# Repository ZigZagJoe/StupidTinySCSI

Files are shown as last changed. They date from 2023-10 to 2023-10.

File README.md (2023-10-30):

StupidTinySCSI
Derived from ZuliSCSI Pico OSHW.

This should be good but has not been 100% validated.

See below for orginal document.....

ZuluSCSI™ Pico Community Edition - Open Source Hardware
========================

This repository contains the KiCAD 7 schematic and PCB design files for the Pico-based ZuluSCSI™ SCSI to SD storage emulator, which is derived from the ZuluSCSI RP2040 board design. Firmware for ZuluSCSI is available at http://github.com/ZuluSCSI/ZuluSCSI-firmware.

This hardware design is licensed under the terms of the strongly reciprocal CERN OHL-S V2 license, which can be viewed in full at https://ohwr.org/cern_ohl_s_v2.txt and https://ohwr.org/cern_ohl_s_v2.pdf. 

ZuluSCSI™ is a registered trademark of Rabbit Hole Computing, and may not be used commercially without the express written consent of Rabbit Hole Computing. Individuals producing ZuluSCSI boards for personal use are hereby granted permission to use the ZuluSCSI trademark in a noncommercial capacity.

_Any_ use of the ZuluSCSI trademark in a **commercial** context requires prior written consent from Rabbit Hole Computing.

ZuluSCSI Pico OSHW board Render (top)

Firmware for ZuluSCSI is licensed under the GNU GPL Version 3, and can be found at https://github.com/zuluscsi/ZuluSCSI-firmware

Generating fabrication files
----------------------------

The component part numbers are stored in KiCAD schematic.
Manufacturing files, including assembly BOM, can be generated using [KiKit](https://github.com/yaqwsx/KiKit).

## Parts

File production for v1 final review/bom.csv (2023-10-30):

Designator | Footprint | Quantity | Value | LCSC Part #
C101, C103, C104, C105, C106, C107, C312 | 0603 | 7 | 100nF | C14663
C111, C209, C211, C215 | 0603 | 4 | 12pF | C38523
C114, C201, C207, C210, C303, C322 | 0805 | 6 | 10uF | C15850
C203, C301, C302 | CP_EIA-6032-15_Kemet-U_Pad2.25x2.35mm_HandSolder | 3 | 220uF
D201, D203, D204 | D_SOD-123 | 3 | D_Schottky | C8598
D302 | 0805 | 1 | LED | C434435
F202 | 1206 | 1 | 500mA Hold | C369160
J101 | DSUB-25_Female_Horizontal_P2.77x2.84mm_EdgePinOffset9.90mm_Housed_MountingHolesOffset11.32mm | 1 | DB25_Female_MountingHoles | N/A
J301 | microSD_HC_Hirose_DM3AT-SF-PEJM5 | 1 | Micro_SD_Card_Det_Hirose_DM3AT
JP301 | SolderJumper-2_P1.3mm_Bridged_RoundedPad1.0x1.5mm | 1 | SCSI_TERM
L201 | Inductor_1008 | 1 | 2.2uH | C86092
L202, L301 | 0603 | 2 | Ferrite_Bead_Small | C1002
R109, R110, R119 | 0603 | 3 | 110 | C22781
R122, R123, R124, R125, R301, R317 | 0603 | 6 | 1k | C21190
R126, R127, R128, R129, R205, R307, R308, R311, R312, R313, R314, R315, R318 | 0603 | 13 | 4k7 | C23162
R201 | 0603 | 1 | 510k | C23192
R202 | 0603 | 1 | 100k | C25803
R304 | 0603 | 1 | 62 | C25252
RN301, RN302 | R_Array_Convex_8x0602 | 2 | 110
U1 | RPi_Pico_WH_headers | 1 | Pico W | N/A
U101, U102, U103 | SSOP_TSSOP-14_4.4x5mm_Pitch0.65mm_PCBWay-MaskClearance0.22mm | 3 | 74LVT125 | C7042
U105, U106 | SSOP_TSSOP-20_5.3x7.2mm_P0.65mm | 2 | 74LVT245 | C7057
U201 | TSOT-23-5 | 1 | LM3674-ADJ | C52027

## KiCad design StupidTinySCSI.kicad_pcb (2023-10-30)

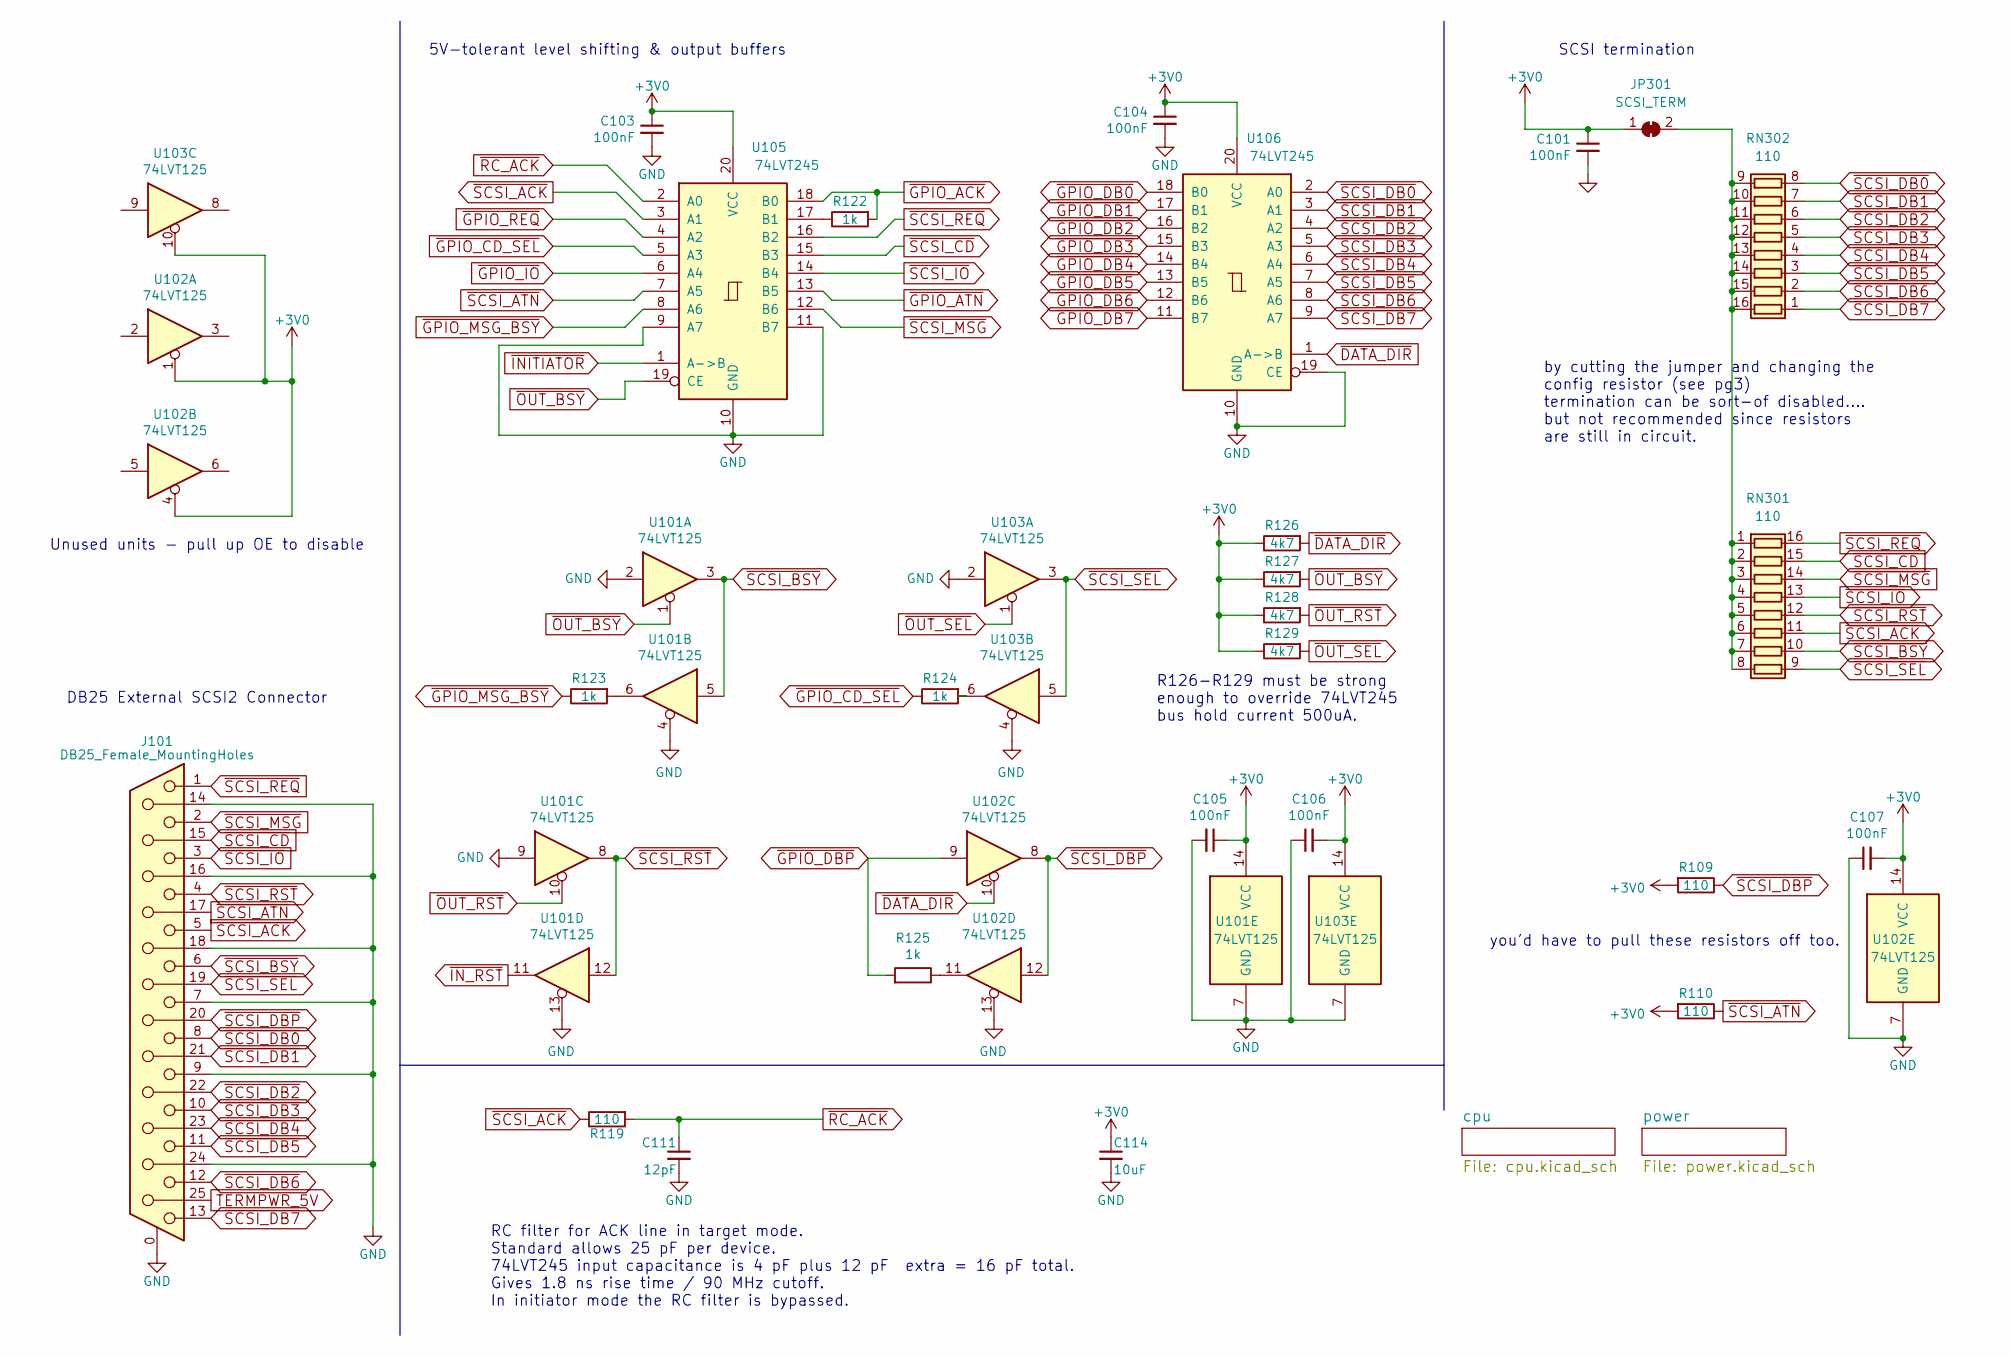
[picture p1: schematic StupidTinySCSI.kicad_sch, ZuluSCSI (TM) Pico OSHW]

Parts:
C101, C103, C104, C105, C106, C107: 100nF; C_0603_1608Metric; PartNumber CL10B104KB8NNWC; LCSC C14663
C111: 12pF; C_0603_1608Metric; PartNumber C0603C120J5GAC7867; LCSC C38523
C114: 10uF; C_0805_2012Metric; PartNumber CL21A106KPFNNNG; LCSC C15850
J101: DB25_Female_MountingHoles; DSUB-25_Female_Horizontal_P2.77x2.84mm_EdgePinOffset9.90mm_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; LCSC N/A
JP301: SCSI_TERM; SolderJumper-2_P1.3mm_Bridged_RoundedPad1.0x1.5mm
R109, R110, R119: 110; R_0603_1608Metric; PartNumber RC0603FR-07110RL; LCSC C22781
R122, R123, R124, R125: 1k; R_0603_1608Metric; PartNumber RC0603JR-071KL; LCSC C21190
R126, R127, R128, R129: 4k7; R_0603_1608Metric; PartNumber RC0603JR-074K7L; LCSC C23162
RN301, RN302: 110; R_Array_Convex_8x0602
U101, U102, U103: 74LVT125; SSOP_TSSOP-14_4.4x5mm_Pitch0.65mm_PCBWay-MaskClearance0.22mm; PartNumber 74LVTH125MTC; LCSC C7042
U105, U106: 74LVT245; SSOP_TSSOP-20_5.3x7.2mm_P0.65mm; PartNumber 74LVT245BBT20-13; LCSC C7057

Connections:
+3V0: C101.1, C103.1, C104.1, C105.1, C106.2, C107.2, C114.1, JP301.1 (A), R109.2, R110.2, R126.1, R127.1, R128.1, R129.1, U101.14 (VCC), U102.1, U102.4, U102.14 (VCC), U103.10, U103.14 (VCC), U105.20 (VCC), U106.20 (VCC); also elsewhere on the board
GND: C101.2, C103.2, C104.2, C105.2, C106.1, C107.1, C111.2, C114.2, J101.0 (PAD), J101.7, J101.9, J101.14, J101.16, J101.18, J101.24, U101.2, U101.4, U101.7 (GND), U101.9, U101.13, U102.7 (GND), U102.13, U103.2, U103.4, U103.7 (GND), U105.9 (A7), U105.10 (GND), U105.11 (B7), U106.10 (GND), U106.19 (CE); also elsewhere on the board
unnamed: JP301.2 (B), RN301.1 (R1.1), RN301.2 (R2.1), RN301.3 (R3.1), RN301.4 (R4.1), RN301.5 (R5.1), RN301.6 (R6.1), RN301.7 (R7.1), RN301.8 (R8.1), RN302.9 (R8.2), RN302.10 (R7.2), RN302.11 (R6.2), RN302.12 (R5.2), RN302.13 (R4.2), RN302.14 (R3.2), RN302.15 (R2.2), RN302.16 (R1.2)
unnamed: R123.2, U101.6
unnamed: R124.2, U103.6
unnamed: R125.1, U102.11
unnamed: R122.1, U105.17 (B1)
TERMPWR_5V: J101.25; also elsewhere on the board
~DATA_DIR: R126.2, U102.10, U106.1 (A->B); also elsewhere on the board
~DBGLOG: U105.4 (A2); also elsewhere on the board
~GPIO_ACK: R122.2, U105.18 (B0); also elsewhere on the board
~GPIO_ATN: U105.1 (A->B), U105.13 (B5); also elsewhere on the board
~GPIO_CD_SEL: R124.1, U105.5 (A3); also elsewhere on the board
~GPIO_DB0: U106.18 (B0); also elsewhere on the board
~GPIO_DB1: U106.17 (B1); also elsewhere on the board
~GPIO_DB2: U106.16 (B2); also elsewhere on the board
~GPIO_DB3: U106.15 (B3); also elsewhere on the board
~GPIO_DB4: U106.14 (B4); also elsewhere on the board
~GPIO_DB5: U106.13 (B5); also elsewhere on the board
~GPIO_DB6: U106.12 (B6); also elsewhere on the board
~GPIO_DB7: U106.11 (B7); also elsewhere on the board
~GPIO_DBP: R125.2, U102.9; also elsewhere on the board
~GPIO_IO: U105.6 (A4); also elsewhere on the board
~GPIO_MSG_BSY: R123.1, U105.8 (A6); also elsewhere on the board
~IN_RST: U101.11; also elsewhere on the board
~OUT_BSY: R127.2, U101.1, U105.19 (CE); also elsewhere on the board
~OUT_RST: R128.2, U101.10; also elsewhere on the board
~OUT_SEL: R129.2, U103.1; also elsewhere on the board
~RC_ACK: C111.1, R119.2, U105.2 (A0)
~SCSI_ACK: J101.5, R119.1, RN301.11 (R6.2), U105.3 (A1)
~SCSI_ATN: J101.17, R110.1, U105.7 (A5)
~SCSI_BSY: J101.6, RN301.10 (R7.2), U101.3, U101.5
~SCSI_CD: J101.15, RN301.15 (R2.2), U105.15 (B3)
~SCSI_DB0: J101.8, RN302.8 (R8.1), U106.2 (A0)
~SCSI_DB1: J101.21, RN302.7 (R7.1), U106.3 (A1)
~SCSI_DB2: J101.22, RN302.6 (R6.1), U106.4 (A2)
~SCSI_DB3: J101.10, RN302.5 (R5.1), U106.5 (A3)
~SCSI_DB4: J101.23, RN302.4 (R4.1), U106.6 (A4)
~SCSI_DB5: J101.11, RN302.3 (R3.1), U106.7 (A5)
~SCSI_DB6: J101.12, RN302.2 (R2.1), U106.8 (A6)
~SCSI_DB7: J101.13, RN302.1 (R1.1), U106.9 (A7)
~SCSI_DBP: J101.20, R109.1, U102.8, U102.12
~SCSI_IO: J101.3, RN301.13 (R4.2), U105.14 (B4)
~SCSI_MSG: J101.2, RN301.14 (R3.2), U105.12 (B6)
~SCSI_REQ: J101.1, RN301.16 (R1.2), U105.16 (B2)
~SCSI_RST: J101.4, RN301.12 (R5.2), U101.8, U101.12
~SCSI_SEL: J101.19, RN301.9 (R8.2), U103.3, U103.5

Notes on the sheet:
SCSI termination
R126-R129 must be strong enough to override 74LVT245 bus hold current 500uA.
5V-tolerant level shifting & output buffers
you'd have to pull these resistors off too.
by cutting the jumper and changing the config resistor (see pg3) termination can be sort-of disabled.... but not recommended since resistors are still in circuit.
Unused units - pull up OE to disable
DB25 External SCSI2 Connector
RC filter for ACK line in target mode. Standard allows 25 pF per device. 74LVT245 input capacitance is 4 pF plus 12 pF extra = 16 pF total. Gives 1.8 ns rise time / 90 MHz cutoff. In initiator mode the RC filter is bypassed.

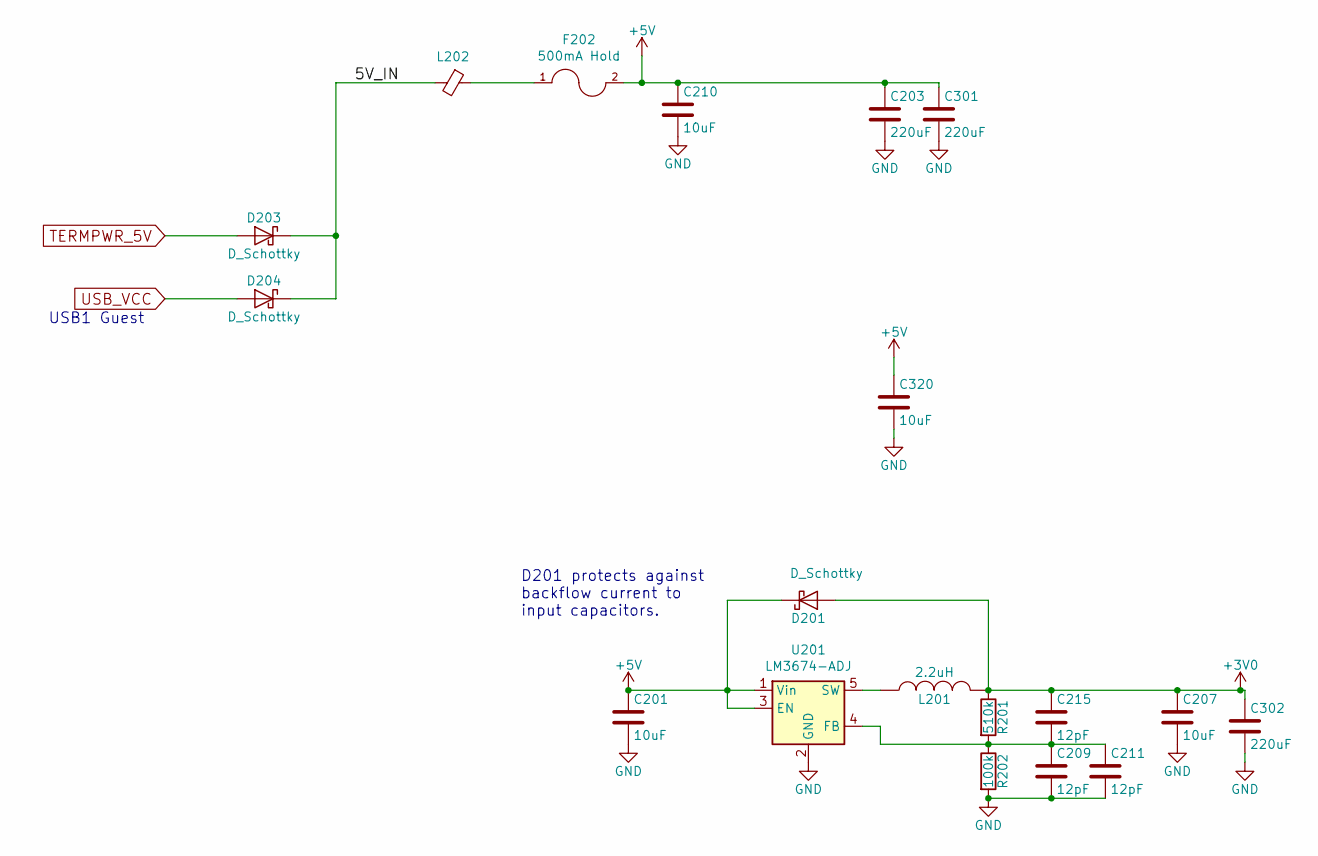
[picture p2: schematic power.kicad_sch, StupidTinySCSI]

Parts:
C201, C207, C210, C320: 10uF; C_0805_2012Metric; PartNumber CL21A106KPFNNNG; LCSC C15850
C203, C301, C302: 220uF; CP_EIA-6032-15_Kemet-U_Pad2.25x2.35mm_HandSolder; PartNumber TAJC227K010RNJ; digikey 478-4774-1-ND
C209, C211, C215: 12pF; C_0603_1608Metric; PartNumber C0603C120J5GAC7867; LCSC C38523
D201, D203, D204: D_Schottky; D_SOD-123; PartNumber MBRX120LF-TP; LCSC C8598
F202: 500mA Hold; Fuse_1206_3216Metric; PartNumber 0ZCJ0050FF2G; LCSC C369160
L201: 2.2uH; Inductor_1008; PartNumber DFE252012P-2R2M=P2; LCSC C86092
L202: Ferrite_Bead_Small; L_0603_1608Metric; PartNumber PE-0603FB601ST; LCSC C1002
R201: 510k; R_0603_1608Metric; PartNumber RC0603FR-07510KL; LCSC C23192
R202: 100k; R_0603_1608Metric; PartNumber RC0603FR-07100KL; LCSC C25803
U201: LM3674-ADJ; TSOT-23-5; PartNumber LM3674MFX-ADJ/NOPB; LCSC C52027

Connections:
+3V0: C207.1, C215.1, C302.1, D201.2 (A), L201.2, R201.1; also elsewhere on the board
+5V: C201.1, C203.1, C210.1, C301.1, D201.1 (K), F202.2, U201.1 (Vin), U201.3 (EN); also elsewhere on the board
/power/5V_IN: D203.1 (K), D204.1 (K), L202.2
GND: C201.2, C203.2, C207.2, C209.2, C210.2, C211.2, C301.2, C302.2, R202.2, U201.2 (GND); also elsewhere on the board
unnamed: F202.1, L202.1
unnamed: C209.1, C211.1, C215.2, R201.2, R202.1, U201.4 (FB)
unnamed: L201.1, U201.5 (SW)
TERMPWR_5V: D203.2 (A); also elsewhere on the board
USB_VCC: D204.2 (A); also elsewhere on the board

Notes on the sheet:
USB1 Guest
D201 protects against backflow current to input capacitors.

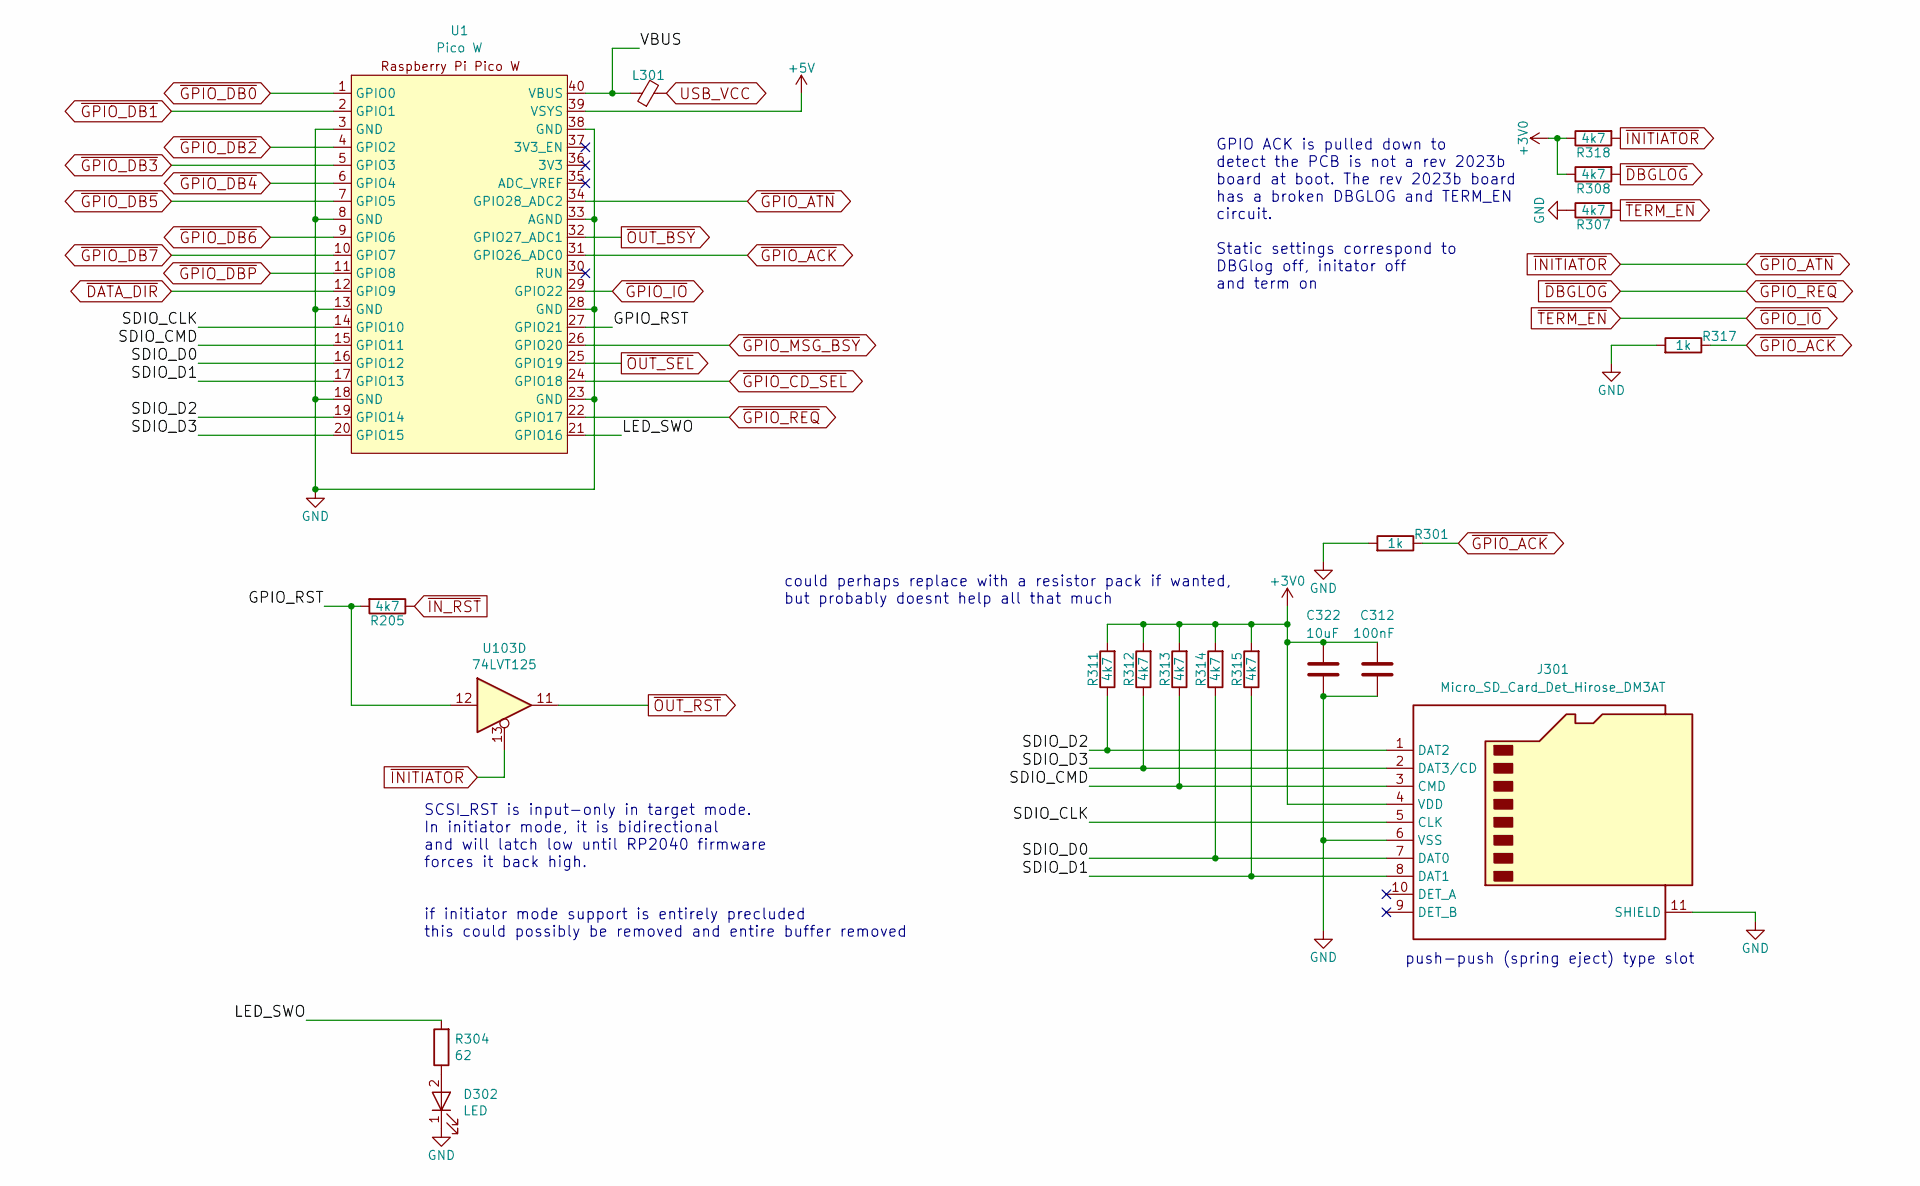
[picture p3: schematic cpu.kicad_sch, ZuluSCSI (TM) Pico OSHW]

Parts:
C312: 100nF; C_0603_1608Metric; PartNumber CL10B104KB8NNWC; LCSC C14663
C322: 10uF; C_0805_2012Metric; PartNumber CL21A106KPFNNNG; LCSC C15850
D302: LED; LED_0805_2012Metric; PartNumber LY R976-PS-36; LCSC C434435
J301: Micro_SD_Card_Det_Hirose_DM3AT; microSD_HC_Hirose_DM3AT-SF-PEJM5
L301: Ferrite_Bead_Small; L_0603_1608Metric; PartNumber PE-0603FB601ST; LCSC C1002
R205, R311, R312, R313, R314, R315: 4k7; R_0603_1608Metric; PartNumber RC0603JR-074K7L; LCSC C23162
R301, R317: 1k; R_0603_1608Metric; PartNumber RC0603JR-071KL; LCSC C21190
R304: 62; R_0603_1608Metric; PartNumber RC0603FR-0762RL; LCSC C25252
R307, R308, R318: 4k7; R_0603_1608Metric
U1: Pico W; RPi_Pico_WH_headers; LCSC N/A
U103: 74LVT125; SSOP_TSSOP-14_4.4x5mm_Pitch0.65mm_PCBWay-MaskClearance0.22mm; PartNumber 74LVTH125MTC; LCSC C7042

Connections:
+3V0: C312.2, C322.2, J301.4 (VDD), R308.1, R311.2, R312.2, R313.2, R314.2, R315.2, R318.1; also elsewhere on the board
+5V: U1.39 (VSYS); also elsewhere on the board
/cpu/GPIO_RST: R205.2, U1.27 (GPIO21), U103.12
/cpu/LED_SWO: R304.2, U1.21 (GPIO16)
/cpu/SDIO_CLK: J301.5 (CLK), U1.14 (GPIO10)
/cpu/SDIO_CMD: J301.3 (CMD), R313.1, U1.15 (GPIO11)
/cpu/SDIO_D0: J301.7 (DAT0), R314.1, U1.16 (GPIO12)
/cpu/SDIO_D1: J301.8 (DAT1), R315.1, U1.17 (GPIO13)
/cpu/SDIO_D2: J301.1 (DAT2), R311.1, U1.19 (GPIO14)
/cpu/SDIO_D3: J301.2 (DAT3/CD), R312.1, U1.20 (GPIO15)
/cpu/VBUS: L301.1, U1.40 (VBUS)
GND: C312.1, C322.1, D302.1 (K), J301.6 (VSS), J301.11 (SHIELD), R301.2, R307.1, R317.2, U1.3 (GND), U1.8 (GND), U1.13 (GND), U1.18 (GND), U1.23 (GND), U1.28 (GND), U1.33 (AGND), U1.38 (GND); also elsewhere on the board
unnamed: D302.2 (A), R304.1
USB_VCC: L301.2; also elsewhere on the board
~DATA_DIR: U1.12 (GPIO9); also elsewhere on the board
~DBGLOG: R308.2, U1.22 (GPIO17); also elsewhere on the board
~GPIO_ACK: R301.1, R317.1, U1.31 (GPIO26_ADC0); also elsewhere on the board
~GPIO_ATN: R318.2, U1.34 (GPIO28_ADC2), U103.13; also elsewhere on the board
~GPIO_CD_SEL: U1.24 (GPIO18); also elsewhere on the board
~GPIO_DB0: U1.1 (GPIO0); also elsewhere on the board
~GPIO_DB1: U1.2 (GPIO1); also elsewhere on the board
~GPIO_DB2: U1.4 (GPIO2); also elsewhere on the board
~GPIO_DB3: U1.5 (GPIO3); also elsewhere on the board
~GPIO_DB4: U1.6 (GPIO4); also elsewhere on the board
~GPIO_DB5: U1.7 (GPIO5); also elsewhere on the board
~GPIO_DB6: U1.9 (GPIO6); also elsewhere on the board
~GPIO_DB7: U1.10 (GPIO7); also elsewhere on the board
~GPIO_DBP: U1.11 (GPIO8); also elsewhere on the board
~GPIO_IO: R307.2, U1.29 (GPIO22); also elsewhere on the board
~GPIO_MSG_BSY: U1.26 (GPIO20); also elsewhere on the board
~IN_RST: R205.1; also elsewhere on the board
~OUT_BSY: U1.32 (GPIO27_ADC1); also elsewhere on the board
~OUT_RST: U103.11; also elsewhere on the board
~OUT_SEL: U1.25 (GPIO19); also elsewhere on the board

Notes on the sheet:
GPIO ACK is pulled down to detect the PCB is not a rev 2023b board at boot. The rev 2023b board has a broken DBGLOG and TERM_EN circuit. Static settings correspond to DBGlog off, initator off and term on
could perhaps replace with a resistor pack if wanted, but probably doesnt help all that much
push-push (spring eject) type slot
SCSI_RST is input-only in target mode. In initiator mode, it is bidirectional and will latch low until RP2040 firmware forces it back high. if initiator mode support is entirely precluded this could possibly be removed and entire buffer removed

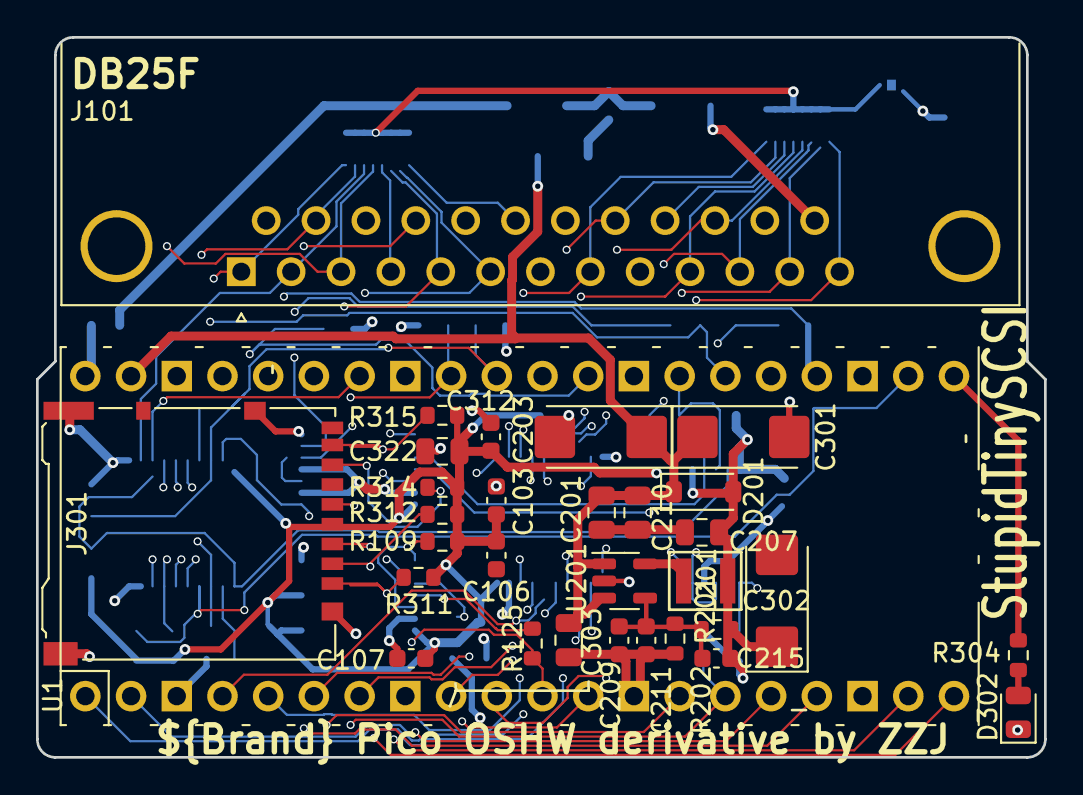
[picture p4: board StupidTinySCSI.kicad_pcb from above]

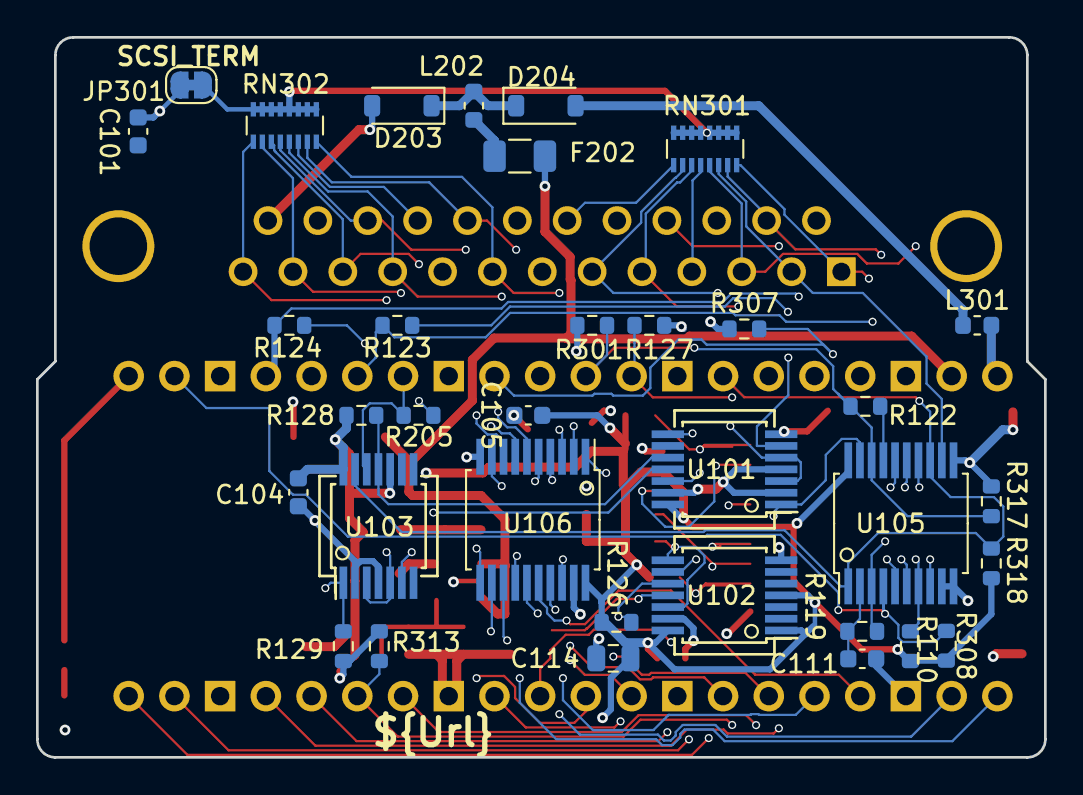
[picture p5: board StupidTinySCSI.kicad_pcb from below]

Board: 4 copper layers, 56.0 x 40.0 mm, 65 parts (34 on the bottom side), 63 nets.

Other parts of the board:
C303: 10uF; C_0805_2012Metric

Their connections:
+5V: C303.1; also elsewhere on the board
GND: C303.2; also elsewhere on the board

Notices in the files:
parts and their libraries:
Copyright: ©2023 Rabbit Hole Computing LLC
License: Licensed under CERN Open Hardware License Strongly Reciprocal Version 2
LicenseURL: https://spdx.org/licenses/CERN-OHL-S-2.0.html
